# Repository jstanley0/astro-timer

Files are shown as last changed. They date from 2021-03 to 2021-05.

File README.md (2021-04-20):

astro-timer
===========

hardware and firmware for an ATMEGAx8-powered astrophotography timer

astro-timer

astro-timer in a 3D-printed enclosure

---

This device controls a camera (in bulb mode) for a sequence of light frames
for astrophotography. The camera is connected to the 2.5mm jack.
The exposure length, exposure count, time between exposures, and optionally
mirror lockup time can be set. Additionally, screen brightness can be adjusted,
and preferences can be saved in NVRAM.

Controls (from left to right):
 - Set button
 - Select button
 - Fancy control knob

Usage:
 - Press the Select button to cycle between parameters (exposure length, time between
   exposures, exposure count, and the options submenu).
   Alternatively, you can hold Select and rotate the knob to move through
   this menu in either direction.
 - The options submenu includes mirror lockup time, half-press setting (never,
   first shot in a series, every shot), brightness, encoder knob direction,
   and battery voltage).
 - Rotate the fancy control knob to adjust the currently visible parameter.
   If this parameter is exposure length or time between exposures, it will be adjusted
   in discrete stops.
 - It is possible to set the minutes and seconds to arbitrary values via the Set button.
   Press Set and the minutes value will flash. Turn the knob to set it to any value, then
   press Set again. The process will repeat for the seconds value.
 - Press the control knob in to start an exposure sequence, or enter/exit the options submenu.
 - You can adjust display brightness at any time by holding Set and turning the knob.
 - Press Set while looking at "Opts" to save current settings to non-volatile memory,
   where they will persist after changing batteries, etc.
 - While the exposure sequence is running,
   - Turn the control knob adjust the display brightness.
   - Press Select to toggle between displaying remaning time vs remaining
     exposure count.
   - Push the control knob to stop the exposure sequence.
 - Set the exposure count to 0 to take an unbounded number of shots. The counter will
   show the number of exposures complete, rather than the number remaining
   (i.e., counting up, not down).
 - Push and hold the control knob to turn the device off. (Press any button to turn it
   back on later.) The device will power itself down after 20 minutes of inactivity.
 
Parts:
 - Atmel ATmega328P microcontroller (the program fits in ATmega88 or larger).
 - 4-digit 7-segment LED display, common anode. The original PCB uses COM-09483 from SparkFun,
   model YSD-439AR6B-35. Other compatible devices include Lite-ON LTC-4627, Para Light A-394,
   Vishay TDCR1050M).
 - Suitable resistors to drive the LEDs (I use 470 ohms)
 - 3V power supply (e.g. 2x AAA batteries)
 - Two momentary-contact switches (Set and Select keys)
 - One rotary encoder (for adjusting parameter values up and down) with switch (Start key)
 - Two NPN transistors (interface to camera) and base resistors (22K)
 - One 32.768kHz watch crystal, 6pf load capacitance
 - And some sort of jack compatible with your camera's remote shutter release port

The wiring is as follows (see KiCad schematic in hardware/)
 - PORTB0..3 (output) = Digit anode drivers
 - PORTB4    (output) = colon / apostrophe anodes
 - PORTB5    (output) = Transistor to camera (full press; tip in Canon connector)
 - PORTB6..7          = 32.768kHz watch crystal
 - PORTC0    (input)  = Rotary encoder CLK
 - PORTC1    (input)  = Rotary encoder DT
 - PORTC2    (input)  = Start key (on rotary encoder)
 - PORTC3    (input)  = Select key
 - PORTC4    (input)  = Set key
 - PORTC5    (output) = Transistor to camera (optional, half press; ring in Canon connector)
 - PORTD0..7 (output) = Segment cathodes (PD7 = A, PD6 = B, ... PD0 = DP)

Compile with AVRGCC.

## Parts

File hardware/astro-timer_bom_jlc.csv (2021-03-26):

Comment | Designator | Footprint | LCSC Part #
100nF | C1,C2 | C_0805_2012Metric | C49678
10nF | C3,C4 | C_0805_2012Metric | C1710
Q_NPN_BEC | Q1,Q2 | SOT-23 | C2146
470 | R8,R7,R6,R5,R4,R3,R2,R1 | R_0805_2012Metric | C17710
22K | R9,R10 | R_0603_1608Metric | C31850
10K | R11,R12,R13,R14,R15 | R_0603_1608Metric | C25804
ATmega328P-AU | U1 | TQFP-32_7x7mm_P0.8mm | C14877

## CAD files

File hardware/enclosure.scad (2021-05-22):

// NOTE: this box fits the version of the PCB in revision 675ee8522adee054eeff6e4886fde3a02e86f080
// the switch positions have been tweaked since then; see comments if building a box for a newly fabbed PCB

pcb_width=65.9;
pcb_length=41.4;

pcb_margin_y=1;
pcb_margin_x=0.4;

pcb_level=13.5;
pcb_thickness=1.6;
control_thickness=6.2;

inside_width=pcb_width+pcb_margin_x*2;
inside_length=pcb_length+pcb_margin_y*2;

inside_height=pcb_level+pcb_thickness+control_thickness;

wall_thickness=1.65;
floor_thickness=1.5;
overlap_thickness=3.5;
overlap_delta=0.25;

screw_sep_x=59.13;
screw_sep_y=34.8;

screw_int_r=2.5;
screw_ext_r=4.8;
screw_depth=8;
screw_ledge_depth=0.5;
screw_ledge_r=3;

standoff_int_r=1.5;
standoff_ext_r=2.5;
standoff_overlap=pcb_thickness*(3/8);

spacer_int_r=1.65;
spacer_int_h=1;
spacer_ext_r=3;

// note: offsets are relative to the bottom and right
    
screen_offset_x=12.84;
screen_offset_y=27.13;
screen_width=40.5;
screen_height=12.88;
screen_margin=0.5;
screen_support_width=2;
screen_support_thickness=2;

sw23_offset_y=5.64; // 5.74 in newest PCB design
sw3_offset_x=33.31; // 33.29
sw2_offset_x=42.36; // 41.98
sw_radius=2;

enc_offset_y=17.55;
enc_offset_x=8.78;
enc_radius=3.5;
enc_dep_radius=5.75;
enc_dep_thickness=0.5;

enc_nub_width=2.5;
enc_nub_height=1.5;
enc_nub_offset_y=11.25;
enc_nub_offset_x=enc_offset_x;

enc_body_width=12;
enc_body_height=14;

jack_offset_y=30.97;
jack_radius=4.8;
jack_height=2.65;

jack_body_size_x=11.5;
jack_body_size_y=6;
jack_body_size_z=5.5;
jack_body_offset_y=jack_offset_y-jack_body_size_y/2;

isp_offset_x=45.46;
isp_offset_y=-pcb_margin_y-wall_thickness-overlap_delta;
isp_width=13.5;
isp_height=10.5;

snap_width=10;
snap_height=2;
snap_margin=0.75;
snap_inset=13;
snap_ext_r=(snap_height + overlap_delta)/2;


module standoff_support(int_r, ext_r)
{
    dist = (inside_length-screw_sep_y)/2;
    translate([-dist, -dist, 0]) {
        cube([dist+int_r, dist+int_r, pcb_level]);
        cube([dist+ext_r, dist, pcb_level]);
        cube([dist, dist+ext_r, pcb_level]);
    }
}

module standoff(rotation)
{
    rotate([0, 0, rotation])
    union()
    {
        cylinder(pcb_level, standoff_ext_r, standoff_ext_r, $fn=32);
        cylinder(pcb_level + standoff_overlap, standoff_int_r, standoff_int_r, $fn=16);
        standoff_support(standoff_int_r, standoff_ext_r);
    }
}

module snap(rotation)
{
    rotate([0, 0, rotation])
    union()
    {
        cube([snap_width, wall_thickness, control_thickness], true);
        translate([0, overlap_delta-snap_height/3, (control_thickness-snap_height)/2])
            rotate([0, 90, 0])
            cylinder(snap_width, snap_height/2, snap_height/2, true, $fn=16);
    }
}

module box()
{
    // coordinate space puts (0, 0, 0) just inside the box
    difference()
    {
        translate([-wall_thickness, -wall_thickness, -floor_thickness])
        {
            cube([inside_width + wall_thickness*2,
                  inside_length + wall_thickness*2,
                  inside_height + floor_thickness]);
        }
        cube([inside_width, inside_length, inside_height]);

        // jack
        translate([inside_width, pcb_margin_y + jack_offset_y, pcb_level + pcb_thickness + jack_height])
            rotate([0, 90, 0])
            cylinder(wall_thickness, jack_radius, jack_radius, $fn=28);
        translate([inside_width + wall_thickness / 2, pcb_margin_y + jack_offset_y, pcb_level + pcb_thickness + jack_height + jack_radius/2])
            cube([wall_thickness, jack_radius*2, jack_radius], true);
        
        // snap holes
        translate([snap_inset, pcb_margin_y/2, pcb_level + pcb_thickness + (snap_height + snap_margin)/2])
            rotate([0, 90, 0])
            cylinder(snap_width+snap_margin*2, snap_ext_r, snap_ext_r, true, $fn=16);
        translate([inside_width-snap_inset, pcb_margin_y/2, pcb_level + pcb_thickness + (snap_height + snap_margin)/2])
            rotate([0, 90, 0])
            cylinder(snap_width+snap_margin*2, snap_ext_r, snap_ext_r, true, $fn=16);
        translate([snap_inset, inside_length - pcb_margin_y/2, pcb_level + pcb_thickness + (snap_height + snap_margin)/2])
            rotate([0, 90, 0])
            cylinder(snap_width+snap_margin*2, snap_ext_r, snap_ext_r, true, $fn=16);
        translate([inside_width-snap_inset, inside_length - pcb_margin_y/2, pcb_level + pcb_thickness + (snap_height + snap_margin)/2])
            rotate([0, 90, 0])
            cylinder(snap_width+snap_margin*2, snap_ext_r, snap_ext_r, true, $fn=16);        
    }
    translate([inside_width/2 - screw_sep_x/2, inside_length/2 - screw_sep_y/2, 0])
        standoff(0);
    translate([inside_width/2 - screw_sep_x/2, inside_length/2 + screw_sep_y/2, 0])
        standoff(270);
    translate([inside_width/2 + screw_sep_x/2, inside_length/2 - screw_sep_y/2, 0])
        standoff(90);
    translate([inside_width/2 + screw_sep_x/2, inside_length/2 + screw_sep_y/2, 0])
        standoff(180);   

    // top-bottom shims, since I had to make the board a little bigger in Y to implement the snaps
    cube([inside_width, pcb_margin_y-pcb_margin_x, pcb_level+pcb_thickness]);
    translate([0, inside_length-(pcb_margin_y-pcb_margin_x), 0])
    cube([inside_width, pcb_margin_y-pcb_margin_x, pcb_level+pcb_thickness]);
    
}
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

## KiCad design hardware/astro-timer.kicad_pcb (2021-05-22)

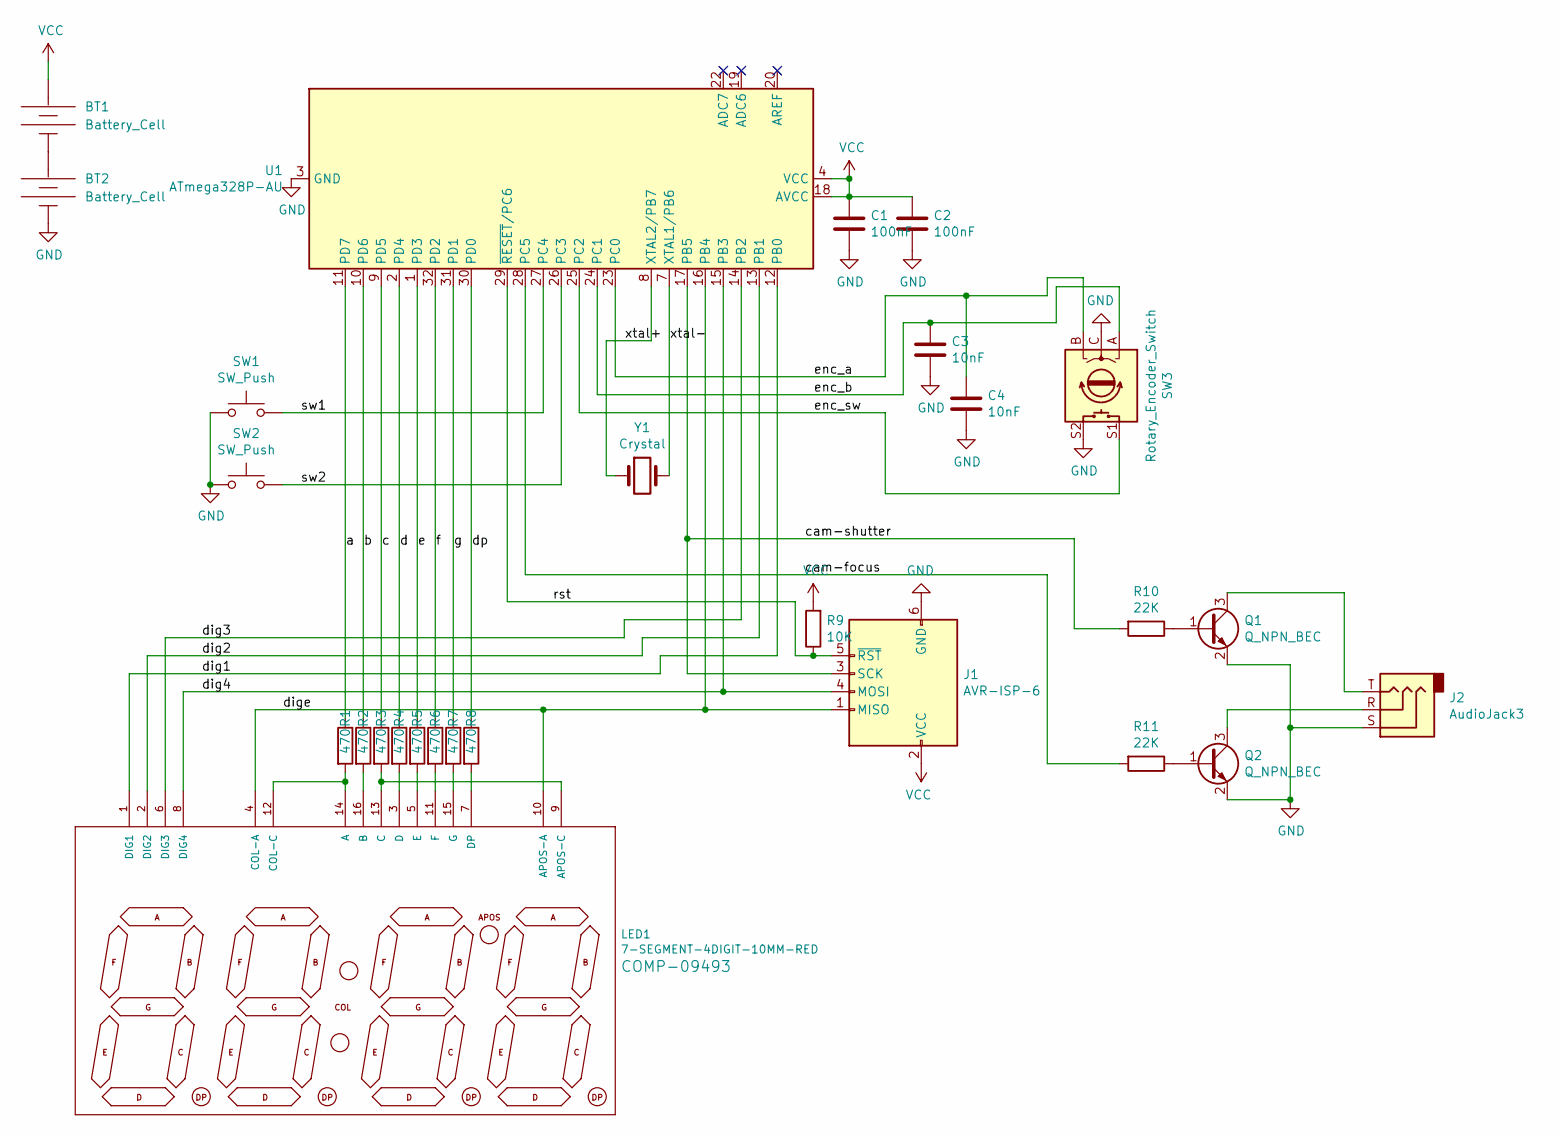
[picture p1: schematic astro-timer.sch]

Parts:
BT1, BT2: Battery_Cell; BATTERY-AAA
C1, C2: 100nF; C_0805_2012Metric; JLC C49678
C3, C4: 10nF; C_0805_2012Metric; JLC C1710
J1: AVR-ISP-6; PinHeader_2x03_P2.54mm_Vertical
J2: AudioJack3; CUI_SJ1-2503A
LED1: 7-SEGMENT-4DIGIT-10MM-RED; 7-SEGMENT-4DIGIT-YOUNGSUN
Q1, Q2: Q_NPN_BEC; SOT-23; JLC C2146
R1, R2, R3, R4, R5, R6, R7, R8: 470; R_0805_2012Metric; JLC C17710
R9: 10K; R_0603_1608Metric; JLC C25804
R10, R11: 22K; R_0603_1608Metric; JLC C31850
SW1, SW2: SW_Push; SW_Tactile_Straight_KSA0Axx1LFTR
SW3: Rotary_Encoder_Switch; EN11HSM1AF15
U1: ATmega328P-AU; TQFP-32_7x7mm_P0.8mm; JLC C14877
Y1: Crystal; Crystal_Round_D2.0mm_Vertical

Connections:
/a: R1.1, U1.11 (PD7)
/b: R2.1, U1.10 (PD6)
/c: R3.1, U1.9 (PD5)
/cam-focus: R11.2, U1.28 (PC5)
/cam-shutter: J1.3 (SCK), R10.2, U1.17 (PB5)
/d: R4.1, U1.2 (PD4)
/dig1: LED1.1 (DIG1), U1.12 (PB0)
/dig2: LED1.2 (DIG2), U1.13 (PB1)
/dig3: LED1.6 (DIG3), U1.14 (PB2)
/dig4: J1.4 (MOSI), LED1.8 (DIG4), U1.15 (PB3)
/dige: J1.1 (MISO), LED1.4 (COL-A), LED1.10 (APOS-A), U1.16 (PB4)
/dp: R8.1, U1.30 (PD0)
/e: R5.1, U1.1 (PD3)
/enc_a: C4.1, SW3.B, U1.23 (PC0)
/enc_b: C3.1, SW3.A, U1.24 (PC1)
/enc_sw: SW3.S1, U1.25 (PC2)
/f: R6.1, U1.32 (PD2)
/g: R7.1, U1.31 (PD1)
/rst: J1.5 (~RST), R9.1, U1.29 (~RESET~/PC6)
/sw1: SW1.2, U1.27 (PC4)
/sw2: SW2.2, U1.26 (PC3)
/xtal+: U1.8 (XTAL2/PB7), Y1.1
/xtal-: U1.7 (XTAL1/PB6), Y1.2
GND: BT2.GND@ (-), C1.2, C2.2, C3.2, C4.2, J1.6 (GND), J2.S, Q1.2 (E), Q2.2 (E), SW1.1, SW2.1, SW3.C, SW3.S2, U1.3 (GND), U1.5 (GND), U1.21 (GND)
unnamed: BT1.GND@ (-), BT2.PWR@ (+)
unnamed: J2.R, Q2.3 (C)
unnamed: J2.T, Q1.3 (C)
unnamed: LED1.3 (D), R4.2
unnamed: LED1.5 (E), R5.2
unnamed: LED1.7 (DP), R8.2
unnamed: LED1.11 (F), R6.2
unnamed: LED1.12 (COL-C), LED1.14 (A), R1.2
unnamed: LED1.9 (APOS-C), LED1.13 (C), R3.2
unnamed: LED1.15 (G), R7.2
unnamed: LED1.16 (B), R2.2
unnamed: Q1.1 (B), R10.1
unnamed: Q2.1 (B), R11.1
VCC: BT1.PWR@ (+), C1.1, C2.1, J1.2 (VCC), R9.2, U1.4 (VCC), U1.6 (VCC), U1.18 (AVCC)

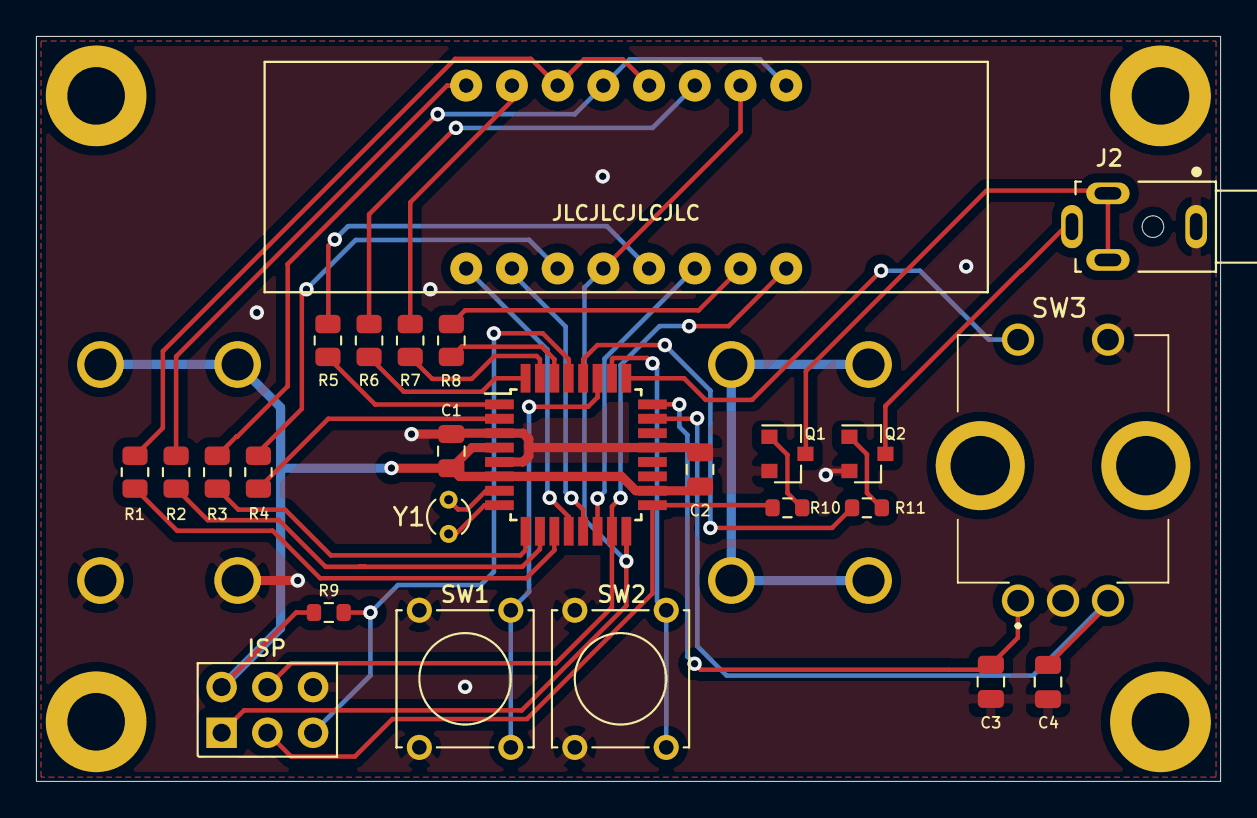
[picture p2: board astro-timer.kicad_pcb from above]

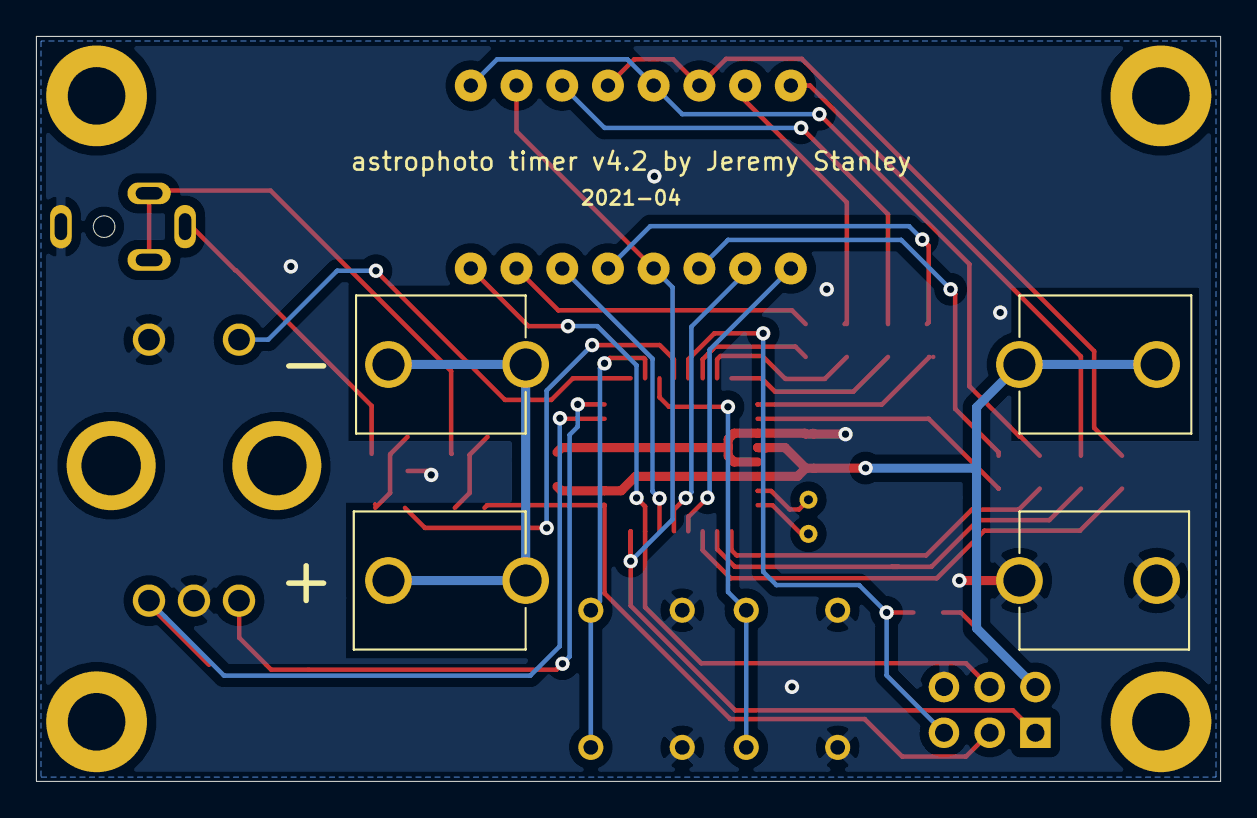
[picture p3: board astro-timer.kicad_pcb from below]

Board: 2 copper layers, 65.8 x 41.4 mm, 27 parts (2 on the bottom side), 38 nets.

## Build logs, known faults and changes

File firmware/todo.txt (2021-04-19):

Exposure Timer MkII TODO:

[x] put in brightness adjustment.

[x] display remaining exposure count.
 [x] option 1: press Select to toggle, like the BF currently does.
 [n] option 2: be a geek, and display counts < 16 in binary on the DP leds. :)
  -> tried it; it's really not that readable.
 [x] option 3: display the count on the left side during the 10-second countdown
     to the next exposure!

[x] ability to save settings in eeprom.
 [x] brightness
 [ ] ???

[x] use idle mode--no busy loops.

[x] save power by eliminating leading zeroes. :D

[x] fix the sleep code; counting sleeps does not really work
    because we don't know that the MCU will actually get to sleep
    between every interrupt.

[x] eliminate state-change latency in auto state changes

[?] see if we can't get rid of that nasty flicker on startup.
  -> maybe initializing the frame buffer would help. :P
   -> you'd think...

[ ] clean up code a bit...
 [x] make symbolic names for all display digits
 [ ] be consistent in '\xZZ' use (and see if it saves us anything)

[x] double-buffer the display to prevent flicker.
  -> will transfer to the frame buffer with interrupts disabled.
   -> actually, I'm skeptical here.  we only draw one character per interrupt.
      so we can have partial displays either way.  so long as I'm drawing the
      display in a spatially localized way, this might not matter.
  --> so I think fixing interrupt priority, increasing the prescaler to 1/64
      and bumping the CPU speed to 2MHz solved the display glitches

[ ] power save mode...
 [x] put MCU in power save mode after idle timeout
   [x] wake up MCU by pushing a button. :D
 [ ] dim and/or turn off LEDs during long exposure?
   -> can currently do this manually...
 [x] soft power off

[ ] real-time clock mode.  depends on power-save mode above.

[x] battery voltage meter
  [ ] better place to *put* the battery voltage meter

[x] fix encoder ISR "backlash" (where it fails to detect a change
    in direction without an extra click, sometimes)

[x] fix a CCW twist going "down" from an inferred stop to the same
    number we are currently staring at :P

[ ] come up with temperature calibration??

[x] make half-press indicator blink, so it seems like something
    is happening
  --> I still don't like this much

[x] wake up mode, with the half-press line

[x] navigate menus by pressing Select and turning the encoder
  --> actually I like pressing and turning the knob
      so you can do either

[x] global brightness adjust by holding Set + turning the knob

[x] table-driven menu navigation (get rid of the error-prone navigation boilerplate!)

[x] make encoder direction configurable on-device so I don't need to flash different firmware
    with an encoder where B leads A

[x] use EESAVE so settings are preserved on program updates

[x] fix half-press bug (if half-press line is asserted when starting an exposure, and then released
    after the full-press line is asserted, the camera stops a bulb exposure; so be like a remote
    switch and keep the former asserted for the duration of the shot, if using it at all)

[x] break less-used things into an options submenu

[x] remember position in opts submenu

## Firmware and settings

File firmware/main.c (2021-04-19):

// Astrophotography Exposure Timer Mk IV
// based on AVR ATMEGAx8 running at 1MHz (default fuses okay)
// build with avr-gcc
//
// Source code (c) 2007-2021 by Jeremy Stanley
// https://github.com/jstanley0/astro-timer
// Licensed under GNU GPL v2 or later

#include <avr/interrupt.h>
#include <avr/pgmspace.h>
#include <avr/boot.h>
#include <util/delay.h>

#include "io.h"
#include "input.h"
#include "clock.h"
#include "display.h"
#include "settings.h"
#include "sensors.h"

// 20 minutes (with 1200 I/O polling cycles per minute)
#define IDLE_TIMEOUT_CYCLES 20 * 1200

const uint16_t stop_table[] PROGMEM = {0, 1, 2, 3, 4, 5, 6, 8, 10, 13, 15, 20, 25, 30, 35, 40, 45, 50, 60, 75, 90, 120, 150, 180, 210, 240, 300, 360, 480, 540, 600, 720, 900, 1200, 1500, 1800, 2100, 2400, 2700, 3000, 3300, 3600, 4500, 5400};
const size_t STOP_TABLE_SIZE = sizeof(stop_table) / sizeof(stop_table[0]);

void adjust_stop(uint8_t min_sec[2], int8_t *current_stop, int8_t encoder_diff)
{
    uint16_t secs = (uint16_t)min_sec[0] * 60 + min_sec[1];
    if (*current_stop < 0) {
        // the value was manually edited and we're possibly between stops, so find the one to start from
        uint8_t i = 0;
        // find the first stop that's greater than or equal to the current time
        while(i < STOP_TABLE_SIZE && pgm_read_word(&stop_table[i]) < secs)
            ++i;
        // if we're going up and are between stops, the stop we found is where we want to increment to
        // with our first tick
        if (encoder_diff > 0 && pgm_read_word(&stop_table[i]) != secs)
            --i;
        *current_stop = i;
    }
    *current_stop += encoder_diff;
    if (*current_stop < 0)
        *current_stop = 0;
    else if (*current_stop >= STOP_TABLE_SIZE)
        *current_stop = STOP_TABLE_SIZE - 1;
    uint16_t new_time = pgm_read_word(&stop_table[*current_stop]);
    min_sec[0] = new_time / 60;
    min_sec[1] = new_time % 60;
}

void increment_num(uint8_t *num, int8_t encoder_diff, uint8_t max)
{
    // spinning the encoder will stop at the low limit (0) and high limit (max)
    // (where max is 59 or 99)
    *num += encoder_diff;
    if (*num > 200)
        *num = 0;   // underflow, probably
    else if (*num > max)
        *num = max;
}

static unsigned char EditNum(uint8_t *num, uint8_t buttons, int8_t encoder_diff, uint8_t max)
{
    if (buttons == 0 && encoder_diff == 0)
        return 0;

    CLOCK_BLINK_RESET();

    // holding Set resets to 0
    if ((buttons & (BUTTON_SET | BUTTON_HOLD)) == (BUTTON_SET | BUTTON_HOLD)) {
        buttons ^= BUTTON_SET;  // don't save/exit in this case
        *num = 0;
    }

    // tapping Select increments by 1 (and holding Select increments by 10)
    if (buttons & BUTTON_SELECT) {
        if (buttons & BUTTON_HOLD)
            *num += 10;
        else
            *num += 1;
    }

    // the encoder increments / decrements by 1, saturating
    // (button taps wrap back to 0)
    if (encoder_diff != 0) {
        increment_num(num, encoder_diff, max);
    } else {
        if (*num > max)
            *num = 0;
    }

    // save with either the Set button or the Start button
    return (buttons & (BUTTON_SET | BUTTON_START));
}

void adjust_brightness(int8_t encoder_diff)
{
    int8_t diff = encoder_diff ? encoder_diff : 1;
    int8_t new_val = (int8_t)bright - diff;
    while (new_val < 0)
        if (encoder_diff == 0)
            new_val += 6;   // wrap if pushing buttons
        else
            new_val = 0;    // clamp if turning encoder
    if (new_val > 5)
        new_val = 5;
    bright = (uint8_t)new_val;
    display_set_brightness(bright);
}

void display_signature_byte(uint8_t addr)
{
    DisplayHex(addr, HIGH_POS);
    DisplayHex(boot_signature_byte_get(addr), LOW_POS);
    display[EXTRA_POS] = COLON;
}

enum State {
    // main menu
    ST_TIME, ST_DELAY, ST_COUNT, ST_OPTS,
    // options menu
    ST_MLU, ST_HPRESS, ST_BRIGHT, ST_ENCODER_DIR, ST_POWER_METER,
    ST_TEMP_SENSOR, ST_SIGNATURE_ROW, ST_SAVED,
    // edit states
    ST_TIME_SET_MINS, ST_TIME_SET_SECS,
    ST_DELAY_SET_MINS, ST_DELAY_SET_SECS,
    ST_COUNT_SET, ST_MLU_SET,
    // run states
    ST_RUN_PRIME, ST_HPRESS_COMPLETE, ST_RUN_MANUAL,
    ST_MLU_PRIME, ST_MLU_WAIT, ST_HPRESS_WAIT,
    ST_RUN_AUTO, ST_WAIT
};

const uint8_t main_menu[] PROGMEM = { ST_TIME, ST_DELAY, ST_COUNT, ST_OPTS };
const uint8_t MAIN_MENU_SIZE = sizeof(main_menu) / sizeof(main_menu[0]);

const uint8_t opts_menu[] PROGMEM = { ST_MLU, ST_HPRESS, ST_BRIGHT, ST_ENCODER_DIR, ST_POWER_METER, ST_TEMP_SENSOR, ST_SIGNATURE_ROW };
const uint8_t OPTS_MENU_SIZE = sizeof(opts_menu) / sizeof(opts_menu[0]);

void InitRun(enum State *state)
{
    gMin = stime[0];
    gSec = stime[1];

    if (gMin > 0 || gSec > 0)
    {
        // count down
        gDirection = -1;
        *state = ST_RUN_AUTO;
    }
    else
    {
        // count up
        gDirection = 1;
        *state = ST_RUN_MANUAL;
    }

    // open the shutter and start the clock
    SHUTTER_ON();
    clock_start();
}

uint8_t init_opts_state(enum State state)
{
    switch(state)
    {
    case ST_POWER_METER:
        turn_adc_on();
        init_power_meter();
        return 1;
    case ST_TEMP_SENSOR:
        turn_adc_on();
        init_temp_sensor();
        return 1;
    default:
        return 0;
    }
}

void exit_opts_state(enum State state)
{
    if (state == ST_POWER_METER || state == ST_TEMP_SENSOR) {
        turn_adc_off();
    }
}

void run()
{
    // init the state machine
    enum State state = ST_TIME;
    enum State prevstate = ST_TIME;
    uint8_t remaining = 0;
    uint8_t cmode = 0;
    int8_t stime_stop = -1;
    int8_t delay_stop = -1;
    uint16_t idle_cycles = 0;
    uint8_t sig = 0;
    uint8_t main_menu_idx = 0;
    uint8_t opts_menu_idx = 0;
    uint8_t exp_count = 0;

    for(;;)
    {
        uint8_t buttons;
        int8_t encoder_diff;
        input_poll(&buttons, &encoder_diff);

        if (state >= ST_RUN_PRIME || buttons || encoder_diff) {
            idle_cycles = 0;
        } else if (++idle_cycles == IDLE_TIMEOUT_CYCLES) {
            turn_adc_off();
            break;
        }

        // soft power-off
        if ((buttons & (BUTTON_START | BUTTON_HOLD)) == (BUTTON_START | BUTTON_HOLD)) {
            turn_adc_off();
            break;
        }

        // global brightness adjust
        if (buttons & BRIGHT_DOWN) {
            adjust_brightness(-1);
            continue;
        }
        if (buttons & BRIGHT_UP) {
            adjust_brightness(1);
            continue;
        }

        // general navigation
        if (buttons & (BUTTON_SELECT | BUTTON_BACK)) {
            if (state <= ST_OPTS) {
                if (buttons & BUTTON_SELECT) {
                    if (++main_menu_idx >= MAIN_MENU_SIZE)
                        main_menu_idx = 0;
                } else if (buttons & BUTTON_BACK) {
                    if (main_menu_idx == 0)
                        main_menu_idx = MAIN_MENU_SIZE - 1;
                    else
                        --main_menu_idx;
                }
                state = pgm_read_byte(&main_menu[main_menu_idx]);
                buttons = 0;
            } else if (state < ST_SAVED) {
                if (buttons & BUTTON_SELECT) {
                    if (++opts_menu_idx >= OPTS_MENU_SIZE)
                        opts_menu_idx = 0;
                } else if (buttons & BUTTON_BACK) {
                    if (opts_menu_idx == 0)
                        opts_menu_idx = OPTS_MENU_SIZE - 1;
                    else
                        --opts_menu_idx;
                }
                exit_opts_state(state);
                state = pgm_read_byte(&opts_menu[opts_menu_idx]);
                init_opts_state(state);
                buttons = 0;
            }
        }

        if (buttons & BUTTON_START) {
            if (state < ST_OPTS) {
                // start exposure sequence
                prevstate = state;
                remaining = count;
                exp_count = 0;
                cmode = (state == ST_COUNT);
                buttons = 0;
                state = ST_RUN_PRIME;
            } else if (state > ST_OPTS && state < ST_SAVED) {
                // leave options submenu
                exit_opts_state(state);
                buttons = 0;
                state = ST_OPTS;
            }
        }

    newstate:
        switch(state)
        {
        case ST_TIME:
            DisplayNum(stime[0], HIGH_POS, 0, 3, 0);
            display[EXTRA_POS] = COLON;
            DisplayNum(stime[1], LOW_POS, 0, 0, 0);
            if (buttons & BUTTON_SET) {
                state = ST_TIME_SET_MINS;
            } else if (encoder_diff) {
                adjust_stop(stime, &stime_stop, encoder_diff);
            }
            break;
        case ST_DELAY:
            DisplayNum(delay[0], HIGH_POS, 0, 3, 1);
            display[EXTRA_POS] = EMPTY;
            DisplayNum(delay[1], LOW_POS, 0, 0, 0);
            if (buttons & BUTTON_SET) {
                state = ST_DELAY_SET_MINS;
            } else if (encoder_diff) {
                adjust_stop(delay, &delay_stop, encoder_diff);
            }
            break;
        case ST_COUNT:
            DisplayAlnum(LETTER_C, count, 0, 0);
            if (buttons & BUTTON_SET) {
                state = ST_COUNT_SET;
            } else if (encoder_diff) {
                increment_num(&count, encoder_diff, 99);
            }
            break;
        case ST_OPTS:
            display[0] = LETTER_O;
            display[1] = LETTER_P;
            display[2] = LETTER_T;
            display[3] = LETTER_S;
            display[EXTRA_POS] = EMPTY;
            if (buttons & BUTTON_START) {
                state = pgm_read_byte(&opts_menu[opts_menu_idx]);
                init_opts_state(state);
            } else if (buttons & BUTTON_SET) {
                Save();
                prevstate = state;
                state = ST_SAVED;
                remaining = 15;
            }
            break;
        case ST_SAVED:
            display[0] = LETTER_S;
            display[1] = LETTER_A;
            display[2] = LETTER_V;
            display[3] = LETTER_E;
            display[4] = EMPTY;
            if (--remaining == 0)
                state = prevstate;
            break;
        // -- options submenu
        case ST_MLU:
            DisplayAlnum(LETTER_L, mlu, 0, 0);
            if (buttons & BUTTON_SET) {
                state = ST_MLU_SET;
            } else if (encoder_diff) {
                increment_num(&mlu, encoder_diff, 99);
            }
            break;
        case ST_HPRESS:
            display[0] = LETTER_H & DECIMAL;
            switch(hpress) {
            case 0:
                display[1] = LETTER_O;
                display[2] = LETTER_F;
                display[3] = LETTER_F;
                break;
            case 1:
                display[1] = LETTER_1;
                display[2] = LETTER_S;
                display[3] = LETTER_T;
                break;
            case 2:
                display[1] = LETTER_A;
                display[2] = LETTER_L;
                display[3] = LETTER_L;
                break;
            }
            if (buttons & BUTTON_SET) {
                hpress += 1;
                if (hpress > 2) hpress = 0;
            } else if (encoder_diff) {
                increment_num(&hpress, encoder_diff, 2);
            }
            break;
        case ST_BRIGHT:
            DisplayAlnum(LETTER_B, 6 - bright, 0, 0);
            if ((buttons & BUTTON_SET) || encoder_diff) {
                adjust_brightness(encoder_diff);
            }
            break;
        case ST_ENCODER_DIR:
            display[0] = LETTER_E;
            display[1] = EMPTY;
            display[2] = (enc_cw < 0) ? MINUS_SIGN : EMPTY;
            display[3] = LETTER_1;
            if ((buttons & BUTTON_SET) || encoder_diff) {
                enc_cw = -enc_cw;
            }
            break;
        case ST_POWER_METER:
            display_power_meter();
            break;
        case ST_TEMP_SENSOR:
            display_temp_sensor();
            break;
        case ST_SIGNATURE_ROW:
            sig = (sig + encoder_diff) & 0x1f;
            display_signature_byte(sig);
            break;
        // -- end options submenu
        case ST_TIME_SET_MINS:
            DisplayNum(stime[0], HIGH_POS, 0x40, 0, 0);
            display[EXTRA_POS] = COLON;
            DisplayNum(stime[1], LOW_POS, 0, 0, 0);
            if (EditNum(&stime[0], buttons, encoder_diff, 99)) {
                state = ST_TIME_SET_SECS;
            }
            break;
        case ST_TIME_SET_SECS:
            DisplayNum(stime[0], HIGH_POS, 0, 0, 0);
            display[EXTRA_POS] = COLON;
            DisplayNum(stime[1], LOW_POS, 0x40, 0, 0);
            if (EditNum(&stime[1], buttons, encoder_diff, 59)) {
                stime_stop = -1;
                state = ST_TIME;
            }
            break;
        case ST_DELAY_SET_MINS:
            DisplayNum(delay[0], HIGH_POS, 0x40, 0, 1);
            display[EXTRA_POS] = EMPTY;
            DisplayNum(delay[1], LOW_POS, 0, 0, 0);
            if (EditNum(&delay[0], buttons, encoder_diff, 99)) {
                state = ST_DELAY_SET_SECS;
            }
            break;
        case ST_DELAY_SET_SECS:
            DisplayNum(delay[0], HIGH_POS, 0, 0, 1);
            display[EXTRA_POS] = EMPTY;
            DisplayNum(delay[1], LOW_POS, 0x40, 0, 0);
            if (EditNum(&delay[1], buttons, encoder_diff, 59)) {
                delay_stop = -1;
                state = ST_DELAY;
            }
            break;
        case ST_COUNT_SET:
            DisplayAlnum(LETTER_C, count, 0x40, 0);
            if (EditNum(&count, buttons, encoder_diff, 99)) {
                state = ST_COUNT;
            }
            break;
        case ST_MLU_SET:
            DisplayAlnum(LETTER_L, mlu, 0x40, 0);
            if (EditNum(&mlu, buttons, encoder_diff, 59)) {
                state = ST_MLU;
            }
            break;
        case ST_RUN_PRIME:
            if (hpress > 1 || (hpress == 1 && remaining == count)) {
                SHUTTER_HALFPRESS_ON();
                gMin = 0;
                gSec = 1;
                gDirection = -1;
                clock_start();
                state = ST_HPRESS_WAIT;
                break;
            }
            // fall through
        case ST_HPRESS_COMPLETE:
            if (mlu > 0) {
                state = ST_MLU_PRIME;
                SHUTTER_ON();
                DisplayAlnum(LETTER_L, mlu, 0, 0);
            } else {
                InitRun(&state);
                goto newstate;
            }
            break;
        case ST_RUN_AUTO:
            if (gDirection == 0) {
                // time has elapsed.  close the shutter and stop the timer.
                SHUTTER_HALFPRESS_OFF();
                SHUTTER_OFF();
                clock_stop();

                if (remaining > 0)
                {
                    if (--remaining == 0)
                    {
                        // we're done.
                        state = prevstate;
                        break;
                    }
                }

                ++exp_count;
                gMin = delay[0];
                gSec = delay[1];
                gDirection = -1;
                state = ST_WAIT;
                clock_start();
                goto newstate;
            }
            // fall through
        case ST_RUN_MANUAL:
            if (cmode == 0) {
                // time left in this exposure
                DisplayNum(gMin, HIGH_POS, 0, 3, 0);
                DisplayNum(gSec, LOW_POS, 0, 0, 1);
            } else {
                // remaining exposures, or count done so far, if unlimited
                DisplayAlnum(LETTER_C, remaining ? remaining : exp_count, 0, 1);
            }
            display[EXTRA_POS] = CLOCK_BLINKING() ? EMPTY : COLON;
            break;
        case ST_MLU_PRIME:
            SHUTTER_HALFPRESS_OFF();
            SHUTTER_OFF();
            gMin = 0;
            gSec = mlu;
            gDirection = -1;
            state = ST_MLU_WAIT;
            clock_start();
            // fall-through
        case ST_MLU_WAIT:
            DisplayAlnum(LETTER_L, gSec, 0, 0);
            if (gDirection == 0)
            {
                // MLU wait period has elapsed
                clock_stop();
                InitRun(&state);
                goto newstate;
            }
            break;
        case ST_HPRESS_WAIT:
            if (TCNT2 & 0x40) {
                display[EXTRA_POS] |= ~APOS;
            } else {
                display[EXTRA_POS] &= APOS;
            }
            if (gDirection == 0) {
                clock_stop();
                state = ST_HPRESS_COMPLETE;
                goto newstate;
            }
            break;
        case ST_WAIT:
            if (cmode == 0) {
                // wait time
                // except, if there are < 10 seconds to go, we will borrow
                // the minutes field to display the remaining exposure count as well
                if (gMin == 0 && gSec < 10) {
                    DisplayNum(remaining ? remaining : exp_count, HIGH_POS, 0, 1, CLOCK_BLINKING() ? 0 : 1);
                    DisplayNum(gSec, LOW_POS, 0, 1, 0);
                } else {
                    DisplayNum(gMin, HIGH_POS, 0, 3, CLOCK_BLINKING() ? 0 : 1);
                    DisplayNum(gSec, LOW_POS, 0, 0, 0);
                }
            } else {
                // remaining exposures
                DisplayAlnum(LETTER_C, remaining ? remaining : exp_count, 0, CLOCK_BLINKING() ? 0 : 4);
            }
            display[EXTRA_POS] = EMPTY;
            if (gDirection == 0)
            {
                // wait period has timed out;
                // stop the timer and start a new cycle
                clock_stop();
                state = ST_RUN_PRIME;
                goto newstate;
            }
            break;
        }

        if (state >= ST_RUN_PRIME) {
            // check keys
            if (buttons & BUTTON_START) {
                // canceled.
                clock_stop();
                SHUTTER_HALFPRESS_OFF();
                SHUTTER_OFF();
                display[EXTRA_POS] |= ~APOS;

                state = cmode ? ST_COUNT : prevstate;
            } else if (buttons & BUTTON_SELECT) {
                // toggle display, time left vs. count left
                cmode ^= 1;
            } else if (buttons & BUTTON_SET || encoder_diff) {
                // adjust brightness
                adjust_brightness(encoder_diff);
            }
        }
    }
}

int main(void)
{
    sysclk_init();
    io_init();
    blip();

    // Load saved state, if any
    Load();

    power_init();
    display_init();
    clock_init();
    input_init();

    sei();

    for(;;)
    {
        // doesn't return unless the device has been idle for a long time, ...
        run();

        // .. in which case we shut down, to save battery power.
        // but we leave a pin change interrupt running, so a button press will wake us up
        acknowledge_power_off();
        power_down();
    }
}

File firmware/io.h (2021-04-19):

#pragma once

#include <avr/io.h>

void sysclk_init();

void io_init();

// Port assignments:
// PORTB0..3 (output) = Digit anode drivers
// PORTB4    (output) = colon / apostrophe anodes
// PORTB5    (output) = Camera shutter output (full-press)
// PORTB6..7          = 32.768kHz watch crystal
// PORTC0    (input)  = Encoder clock
// PORTC1    (input)  = Encoder data
// PORTC2    (input)  = Start (encoder) key
// PORTC3    (input)  = Select key
// PORTC4    (input)  = Set key
// PORTC5    (output) = Camera shutter output (half-press)
// PORTD0..7 (output) = Segment cathodes (PD7 = A, PD6 = B, ... PD0 = DP)

// for portability, please put all explicit port references here and init_io()
#define DIGITS_OFF()   PORTB &= 0b11100000;
#define DIGIT_ON(x)    PORTB |= (1 << x)

#define SHUTTER_OFF()  PORTB &= ~(1 << PB5)
#define SHUTTER_ON()   PORTB |= (1 << PB5)

#define SHUTTER_HALFPRESS_OFF()  PORTC &= ~(1 << PC5)
#define SHUTTER_HALFPRESS_ON()   PORTC |= (1 << PC5)

#define DIGIT_VALUE(x) PORTD = x

#define BUTTON_STATE() ((PINC & 0b11100) >> 2)

// note: in contravention of my comment above, input.c uses an explicit pin-change interrupt vector :P

// one-bit printf debugging...
void blip();

// shut down unnecessary peripherals to save power
void power_init();

// let the user know we're turning off
void acknowledge_power_off();

// to save power if the device is left idle too long
void power_down();

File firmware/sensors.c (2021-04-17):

#include "io.h"
#include "display.h"

void turn_adc_on()
{
    PRR &= ~(1 << PRADC);
    // enable ADC, 1/32 prescaler, 62.5kHz
    ADCSRA |= (1 << ADEN) | (1 << ADPS2) | (1 << ADPS0);
}

void turn_adc_off()
{
    ADCSRA &= ~(1 << ADEN);
    PRR |= (1 << PRADC);
}

void init_power_meter()
{
    // AVCC reference, 1.1V input
    ADMUX = (1 << REFS0) | (1 << MUX3) | (1 << MUX2) | (1 << MUX1);
}

uint16_t sample_adc()
{
    uint16_t sam = 0;
    if (ADCSRA & (1 << ADIF)) {
        sam = ADCW;
        ADCSRA |= (1 << ADIF);
    }
    ADCSRA |= (1 << ADSC);
    return sam;
}

void display_power_meter()
{
    uint16_t sam = sample_adc();
    if (sam) {
        // VCC = 1.1V * 1024 / adc; we will retrieve hundredths here
        uint16_t cv = (1024L * 110) / sam;
        // since the AVR's voltage range is 1.8 ... 5.5, I'm not going to worry about >= 10 V
        Display3(cv, LETTER_v, 0, 0);
    }
}

void init_temp_sensor()
{
    // 1.1v reference, temperature sensor input
    ADMUX = (1 << REFS1) | (1 << REFS0) | (1 << MUX3);
}

void display_temp_sensor()
{
    // it turns out there *aren't* factory calibration values stored in the signature row
    // so I will just display the raw sample for now, as the datasheet examples are way off
    // I will need two readings at widely separated temperatures to compute the slope and y-intercept
    uint16_t sam = sample_adc();
    if (sam) {
        Display3(sam, EMPTY, 99, 1);
    }
}

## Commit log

2021-02-27 create schematic and PCB, update code to work with new hardware
    my original hardware was lost. I designed a new PCB and had it
    manufactured, then assembled the hardware. some parts have changed,
    based on what I had on hand:
    - the MCU is now an ATmega168. the code would still fit on a '48
    and all you'd need to do to use one (or, for that matter, an '88
    or '328) is to edit the Makefile
    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
    [astro-timer.kicad_pcb, astro-timer.sch]
2021-03-02 changing everything, nothing works yet
    [astro-timer.kicad_pcb, astro-timer.sch]
2021-03-02 this is gonna be lit
    [astro-timer.kicad_pcb, astro-timer.sch]
2021-03-02 creeping toward a layout
    [astro-timer.kicad_pcb, astro-timer.sch]
2021-03-02 improved battery layout
    [astro-timer.kicad_pcb, astro-timer.sch]
2021-03-02 moar pcb tweaks
    [astro-timer.kicad_pcb, astro-timer.sch]
2021-03-03 center the display on the board
    srsly why do I draw traces and *then* notice something like that
    [astro-timer.kicad_pcb]
2021-03-04 add crystal caps
    and do a bit of odd routing to put a ground plane under
    the crystal, while we're at it
    the prior version of this device worked fine without either
    of these things, but the datasheet asks for both, and since
    I'm revising the board anyway
    [astro-timer.kicad_pcb, astro-timer.sch]
2021-03-04 zomg how do I fail to notice the resistors are misaligned before drawing traces
    [astro-timer.kicad_pcb]
2021-03-04 I must have changed _something_
    [astro-timer.kicad_pcb]
2021-03-04 forgot to redo the copper pours
    [astro-timer.kicad_pcb]
2021-03-04 fix battery footprint
    sparkfun's library made them 0.02" too wide
    maybe that doesn't matter; maybe it was intentional
    but I'm going by the book here
    [astro-timer.kicad_pcb]
2021-03-04 battery footprint tweaks
    the datasheet also specified a slightly larger hole size
    [astro-timer.kicad_pcb]
2021-03-05 firmware refactor
    and an initial stab at reading the encoder
    (spoiler: it doesn't work)
    [display.c, input.c, io.c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]
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2021-03-06 implement quick-set encoder stops
    i.e., when you want to quickly change the exposure time to the next
    stop up or down, a single click of the encoder knob is all it takes.
    you don't need to press SET unless you want to set a specific MM:SS
    value (and you can use the encoder knob for that too, with each
    value moving up/down with each click of the knob).
    also make an attempt at debouncing the encoder by not reporting any
    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
2021-03-06 disable pin-change interrupt during debouncing blackout
    my hope was this would reduce display glitchiness while rotating
    the encoder at the lowest brightness level, because it's clear
    sometimes the "turn off" interrupt is being missed
    it didn't seem to, but it does seem to work a bit better in
    terms of debouncing, so
    [display.c, input.c]
2021-03-06 terrible hack to reduce visual glitches at low brightness
    at low brightness, the interrupt that turns the LEDs off occurs
    very soon after the one that turned them on, and if the processor
    is busy handling pin-change interrupts from the encoder, it can
    be missed entirely. this results in a digit briefly appearing
    at maximum brightness, exactly the kind of visual sparkle you
    would not want to see when operating this thing at minimum
    brightness.
    ... so set another compare-match interrupt to turn the LEDs off
    a bit later. then at least the sparkles will be at the second-
    lowest brightness level instead of the highest
    [display.c]
2021-03-06 fix display glitches frd
    the blanking interrupt was not "missed" as the last commit
    surmised. it just ran in the wrong order relative to
    the refresh interrupt.
    the problem occurred when both the overflow and compare
    match A interrupt flags were set before either vector ran
    (because the CPU was busy paying attention to a pin change
    interrupt or whatever).
    this commit ensures the refresh interrupt vector has a
    higher priority than the blanking interrupt
    [display.c]
2021-03-07 support discrete encoder
    the current hardware uses an encoder on a breakout board with
    discrete pullup resistors, but the planned update (and PCB
    currently in hardware/) uses a discrete encoder on the same
    board. I've verified that it works with the AVR's integrated
    pullup resistors
2021-03-09 tweak firmware to support LTC-4627JF display
    the pinouts are similar, but it has three fewer pins and it
    multiplexes the colon and decimal point in ways slightly
    differently than I did, but fortunately not incompatibly
    nice to have a second supplier for this part, because I have
    not been able to find the Young Sun unit anywhere except on
    SparkFun
    it's worth noting that the PCB should also be compatible with
    common cathode displays like the LTC-4727JR with a code change
    to invert the digit and segment drivers
    [io.c]
2021-03-09 plex apostrophe with C segment
    because why not, that's how Lite-On does it
    also tweak the ground plane keepouts under the battery clips
    [astro-timer.kicad_pcb, astro-timer.sch]
2021-03-11 tweak brightness table
    the timer priority adjustment that got rid of the bright sparkles
    in the lowest brightness caused the opposite problem at the
    highest brightness level. fortunately, there is very little
    visual difference between a 90% duty cycle and a 99% duty cycle.
    so just give ourselves some time to separate the two events.
    [display.c]
2021-03-12 use two NPN transistors to switch both focus and shutter lines
    pros:
    - lower power consumption -> better battery life. the optocoupler
    LED can easily use more power than the rest of the entire circuit
    - focus line control (a dual-channel optocoupler could do this too,
    but I don't have any on hand)
    - I don't have a particular use for this but if I want this
    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
    [astro-timer.kicad_pcb, astro-timer.sch]
2021-03-14 SMT version
    because I feel like trying out JLC's assembly service
    [astro-timer.kicad_pcb, astro-timer.sch]
2021-03-15 jlc part numbers
    [astro-timer.kicad_pcb, astro-timer.sch]
2021-03-15 fix QFN clearance and use THT crystal
    JLC doesn't have a suitable one
    and the load capacitors aren't needed if a 6pf crystal is used
    [astro-timer.kicad_pcb, astro-timer.sch]
2021-03-15 add RC filter circuit for rotary encoder
    seems to work pretty well on a breadboard anyway
    [astro-timer.kicad_pcb, astro-timer.sch]
2021-03-15 felt a bit uncomfortable routing a trace under an 0805
    [astro-timer.kicad_pcb]
2021-03-15 lol whoops that via can't be there
    [astro-timer.kicad_pcb]
2021-03-15 add 10K external pullup on ~RESET
    [astro-timer.kicad_pcb, astro-timer.sch]
2021-03-15 use more common 0603 package for low-current resistors
    [astro-timer.kicad_pcb, astro-timer.sch]
2021-03-15 idk quite what I changed but this is the version I sent to the fab
    [astro-timer.kicad_pcb]
2021-03-19 shut down after idle timeout
    I'm pretty sure this thing was on in my camera bag all night,
    because the power switch is easy to press accidentally.
    fortunately the AVR is very good at powering itself down
    and consumes a miniscule amount of power with just a pin-change
    interrupt running to wake it up.
    I measured a power consumption of like a fifth of a microamp
    while this was shut down. if I flip the power switch off for a
    few seconds and then back on, it's _still sleeping_, presumably
    because the 100nf capacitor on the power rails has kept it
    in that state!
    [io.c, io.h, main.c]
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2021-03-22 increase ISP header and filter cap clearance
    wish I'd noticed these issues before I sent the gerbers to the fab
    [astro-timer.kicad_pcb]
2021-03-22 add a bit more clearance from R1 and R2 to the battery
    [astro-timer.kicad_pcb]
2021-03-22 a bit more clearance
    and why did I like the duckling arrangement
    [astro-timer.kicad_pcb]
2021-03-22 tweaks!
    this is a perfectionist's black hole
    [astro-timer.kicad_pcb]
2021-03-22 tweaks. and fab files
    [astro-timer.kicad_pcb, astro-timer_bom_jlc.csv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]
2021-03-22 update footprint placement
    [astro-timer_cpl_jlc.csv]
2021-03-22 label things
    I thought I didn't need them on parts I was going to have
    the PCB house mount, but it occurs to me that if they fail to
    do so for whatever reason, it'd be nice to know what goes where
    [astro-timer.kicad_pcb]
2021-03-26 firmware update for smt edition
    there are just two tac switches and one encoder+switch
    the encoder A and B inputs have external pull-up resistors
    but the encoder switch does not
    somehow the two tac switches got, erm, switched
    the 6pf 32kHz crystal can take the better part of a second to
    start cold, so spin the display while we're waiting for this
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2021-03-26 make room for the crystal to lie flat on the board
    [astro-timer.kicad_pcb, astro-timer.sch]
2021-03-26 make Set and Start buttons progress through EditNum
    holding Set resets to 0, and Select increments by 1
    (or 10 when held). of course using Select for this is
    vestigial anyhow, because the encoder is much nicer.
    I guess I'm leaving the capability to not use it,
    in case I find it wigs out on me some night.
    also fix a bug in display_spin() that I haven't actually witnessed
    because my crystal doesn't take *that* long to start ticking
    [display.c, main.c]
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2021-04-07 run at 2MHz, make display a bit more robust
    the CPU could barely keep up at 1MHz and visual glitches
    resulted. at 8MHz things were fine but there was a noticeable
    power consumption hit. 2MHz feels like a good balance.
    this update increases the number of brightness levels to 6.
    it also buffers the update of OCR0B until the display is
    turned off, which avoids visual glitches while changing
    brightness
    [display.c, input.c, io.c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]
2021-04-12 openscad enclosure
    kind of snaps together and uses two M3 screws + sink-in threaded
    inserts to attach
    [enclosure.scad]
2021-04-13 tweak enclosure
    - margins around the jack body were way wider than necessary
    - screen support doesn't need to be as thick as the overlap
    - increase overlap just a bit
    [enclosure.scad]
2021-04-13 make ISP hole functional
    because I don't want to have to unscrew the lid to program
    my device
    (note that "production" devices don't have an ISP header and
    are flashed using pogo pins, outside the box of course))
    [enclosure.scad]
2021-04-13 fix jack position
    [enclosure.scad]
2021-04-14 soft power-off
    holding the start button down will display "OFF" and enter
    power save mode
    as the measured power consumption is ~100 nA, which is
    well below the batteries' self-discharge rate, there
    really isn't a need for a hard power switch--so I think
    I will omit it from future boards
    also fix a bug causing shorter button-holds to accumulate into
    one long enough to count as a "hold" - how did that bug survive
    for fourteen years?
    and since the brightness now has six levels, I think it makes
    sense for the encoder to control brightness during an exposure
    rather than toggle between remaining count/remaining time
    [input.c, io.c, io.h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]
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2021-04-15 detect falling edge
    seems to reduce the double-decrement problem I was seeing
    [input.c]
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2021-04-15 chasing waterfalls
    honestly I probably just damaged my encoder by pushing down too
    hard on it trying to fit a badly-fitting 3D-printed knob on it
    because I didn't remember this device behaving so poorly
    and my other one works mostly okay
    this maybe helps a little though? I really don't have a good way
    of quantifying this, and also I screwed up by not putting
    test points on the PCB that I can hook oscilloscope probes up to
    because I really would like to see WTF is going on here
    [input.c]
2021-04-15 find an encoder-reading ISR that works better than mine
    still see an occasional missed click but on the whole
    it seems to be a lot cleaner
    [input.c]
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2021-04-15 cleanup standoff support
    [enclosure.scad]
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2021-04-18 add half-press support
    the new "H" setting has three options:
    * Off, which is equivalent to before: the half-press (ring)
    line is never switched;
    * 1st: a half-press is simulated before the first exposure.
    useful for waking the camera up before an exposure sequence
    (the first frame was a second shorter than the others before)
    * All: a half-press is simulated before each exposure. possibly
    useful if you're doing daytime photography and you want
    autofocus to happen
    [main.c]
2021-04-18 fix stop inference bug
    when the encoder is rotated, ensure we move to the next stop
    in the sequence when the time after the value is edited manually
    and may be between stops
    [main.c]
2021-04-18 navigate menus by push+twist encoder knob
    also (hopefully) fix the situation where a missed encoder
    pin-change event causes the ISR to get out of sync and
    require two clicks to register a change in direction
    (by only resetting encoder_cycle while possibly in detent)
    and make the half-press indicator blink, so it appears
    something is happening
    [input.c, main.c]
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2021-04-19 overhaul menu system, make encoder dir configurable on-device
    * less-commonly used items have been moved to an options submenu
    * both menu orders are table-driven, eliminating the error-prone
    navigation boilerplate
    * the encoder direction is configurable on-device and saved in
    EEPROM, so the same firmware can be flashed to devices where
    B leads A or vice versa
    * the EESAVE fuse bit has been set, so configuration survives
    firmware updates
    * if half-press is enabled, it is maintained throughout the
    length of the exposure (as I discovered my Rebel T3i would
    cancel the exposure otherwise)
    [input.c, io.h, main.c]
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2021-04-20 fix hold logic bug
    I accidentally all the other synthetic input bits
    [input.c]
2021-04-20 lose the hard power switch, lose the screws
    make the enclosure snap together!
    also get rid of the external pullups on the rotary encoder,
    so if it stops between detents, they no longer pull battery
    power while the device sleeps
    [astro-timer.kicad_pcb, astro-timer.sch, enclosure.scad]
2021-04-20 rework snaps
    they stuck out too far and some of them broke off
    also the "window" in the box doesn't look great and isn't
    really necessary; this design snaps together and comes apart
    without needing to push through the gaps
    [enclosure.scad]
2021-05-22 tweak enclosure snap
    [enclosure.scad]
2021-05-22 tweak pcb
    [astro-timer.kicad_pcb]
2025-04-27 require two buttons to be held to turn on
    to avoid spurious wakeups in the camera bag, which
    have been pretty common :(
    [io.c]
